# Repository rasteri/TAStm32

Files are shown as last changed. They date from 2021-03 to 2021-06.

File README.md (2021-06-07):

# TAStm32
Please see the "Projects" section for an overview of the current status of this project!

Please see the "Wiki" section for the technical details of the serial communication protocol!

### Overview

This project aims to create an easy-to-use, multi-system TAS replay device to be used on actual consoles. The name of this project comes from the fact that it is powered by a STM32F4 microcontroller.

### Prerequisites

First clone or download this repository

#### Get Python3!
Install the [latest Python 3 release](https://www.python.org/downloads/)

(You may need to log out/log in to refresh the PATH variable)

Then install the required python modules with the following command:

    python3 -m pip install -r python/requirements.txt
    
#### Linux users -- make sure you are in the dialout and plugdev groups!
    
### Compilation

#### Linux
    apt install gcc-arm-none-eabi binutils-arm-none-eabi libnewlib-arm-none-eabi
OR the equivalent in your distribution.

Then : 

    make v3
    
Or : 

    make v4
    
Depending on if you have a v3 or v4 board. (v4s came out around July 2021)

#### Windows

1. Right-click on the project > Build Configurations > Set Active, then click "Release v3" or "Release v4" depending on your board version. (v4s came out around July 2021)
1. Project > Build Project and check that the console shows no errors. The last line before "build finished" should be "arm-atollic-eabi-objcopy -O ihex TAStm32.elf TAStm32.hex".

### Flashing the firmware

#### Linux
    apt install dfu-util
OR the equivalent in your distribution

    make flash

#### Windows
1. Install Atollic TrueStudio
1. Install STM32CubeProgrammer
1. Open up the command prompt
1. Run setenv.bat included in the root directory
1. Run update.bat included in the root directory

### Usage

Dumped TAS movies are available in the [TASBot projects repo](https://github.com/dwangoac/TASBot-Projects/tree/master/replayfiles)

[Scripts to dump your own TASes](https://github.com/dwangoac/TASBot-Projects/blob/master/Dump_Scripts/)

Once you've prepared a movie dump, use it with the TAStm32. Here is one example example is here:

    python3 tastm32.py --console snes --players 1,5 --dpcm --clock 14 --transition 2123 A --blank 1 smb3_agdq.r16m

### Special Thanks
#### TheMas3212 - Aided with all things python, designing the serial communication protocol, helping with PCB design, and debugging throughout the whole process.
#### CraftedCart - Designed the awesome-looking 3D case
#### total (@tewtal) - Helped with NES/SNES protocol and debugging. Provided his code as a reference
#### booto (@booto) - Helped fix N64/GC protocols, serial-over-USB, and debugging
#### rasteri (@rasteri) - Standalone USB playback, v4 board, and more!
#### Skippy - Pretty much helped a little bit with everything: including software, hardware, advice on proper tools, and more!

dwangoAC (@dwangoac) - warmly accepting me into the TASBot community

micro500 (@micro500) - spent a lot of time teaching me how console replay devices work at a low level

true - for teaching me hardware concepts, helping me choose the perfect MCU for the job, and explaining a lot of low-level things to me

Tien Majerle (@MaJerle) - the owner of https://stm32f4-discovery.net/ helped me with the function which jumps to the DFU bootloader code

Ilari - for being an extraordinary wealth of knowledge on most topics

Serisium (@serisium) - helped with debugging and PCB design

rcombs (@rcombs) - helped with optimizing the N64 protocol

Sauraen (@sauraen) - Linux setup and installation notes, multiplayer GC/N64 support, misc. GC/N64 improvements

Derf - worked on debugging the genesis protocol together

sspx (@SuperSpyTX) - For help with finding a bug in the N64 controller identity code.

#### If I accidentally forgot to credit you, please let me know so I can fix it!

 - Ownasaurus

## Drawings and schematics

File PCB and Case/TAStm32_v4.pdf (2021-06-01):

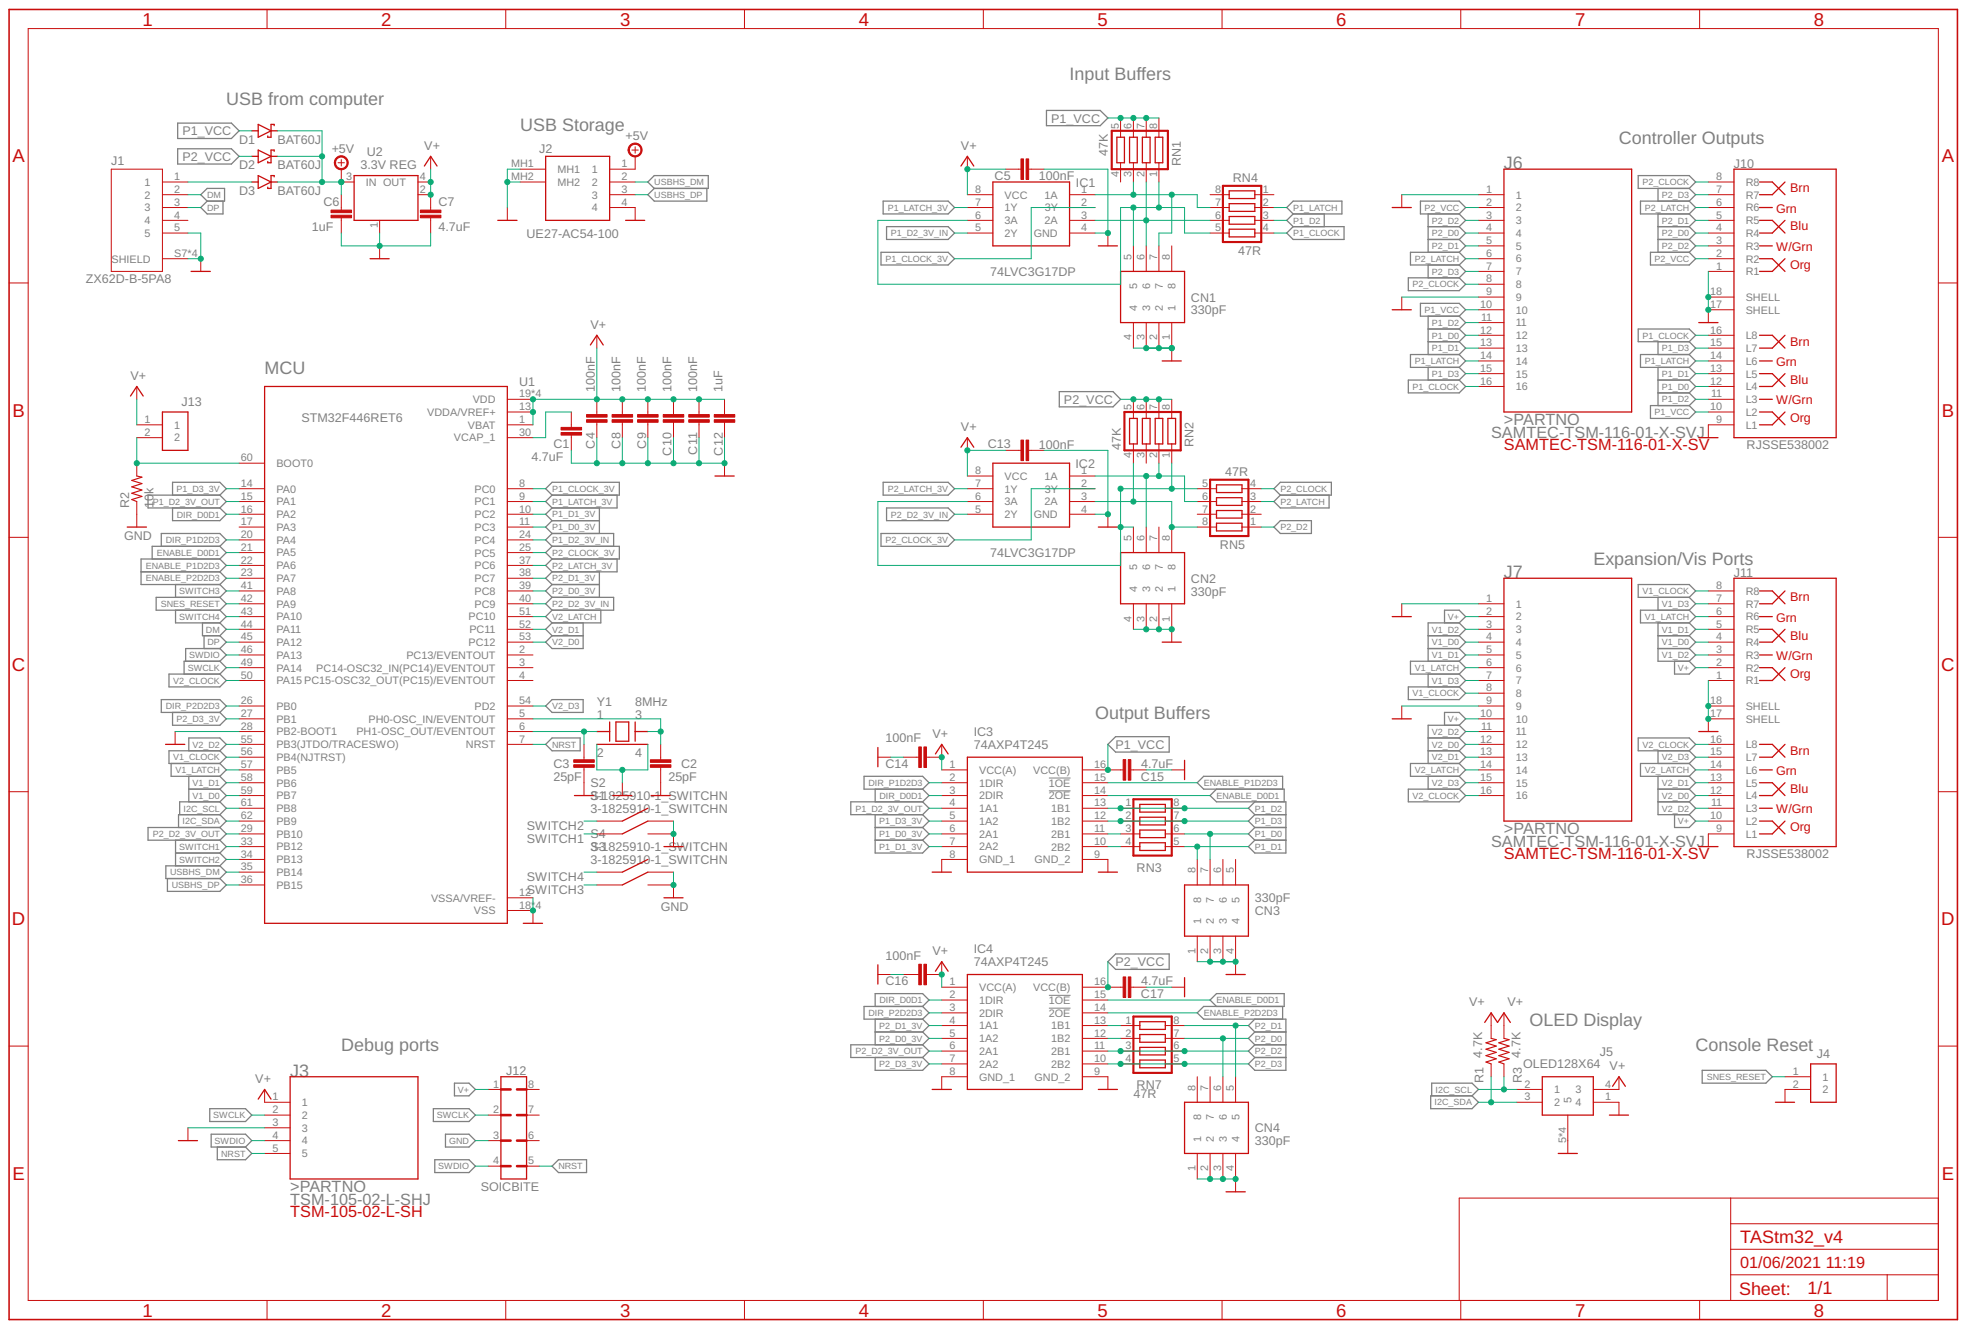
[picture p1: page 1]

Org Blu Brn W/Grn Grn

ENABLE_D0D1 | 25 PC6 P2_CLOCK_3V 37 PC7

ENABLE_P1D2D3 | P2_LATCH_3V

DIR_D0D1 3 | 1OE | ENABLE_D0D1
DIR_P2D2D3 4 | 2OE 1B1 1B2 2B1 2B2 | 13 | ENABLE_P2D2D3
P2_D1_3V 5 | | 12 2 | 7 | P2_D1
P2_D0_3V | | | | P2_D0
6 P2_D2_3V_OUT | | 11 3 | 6 | | P2_D2

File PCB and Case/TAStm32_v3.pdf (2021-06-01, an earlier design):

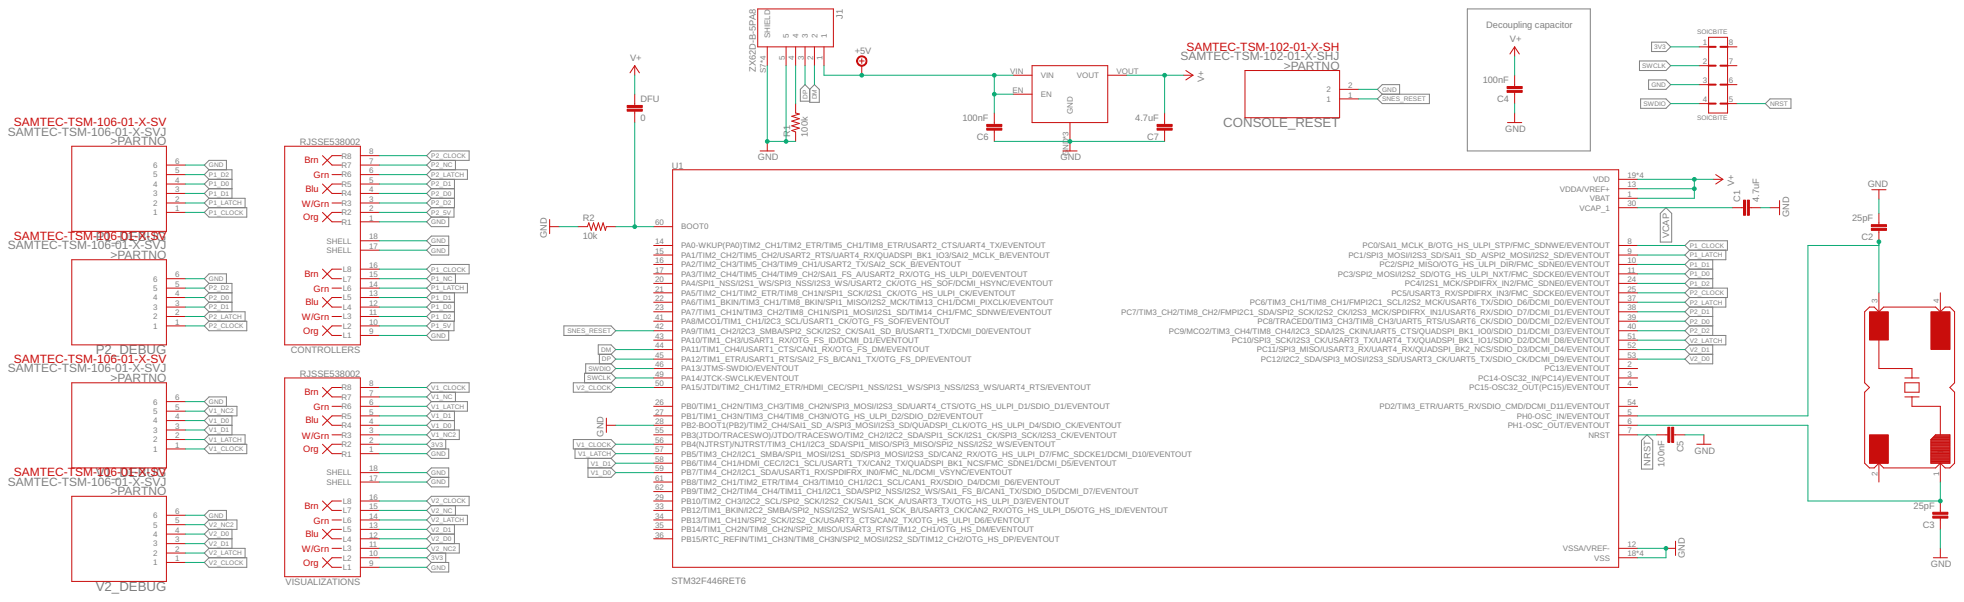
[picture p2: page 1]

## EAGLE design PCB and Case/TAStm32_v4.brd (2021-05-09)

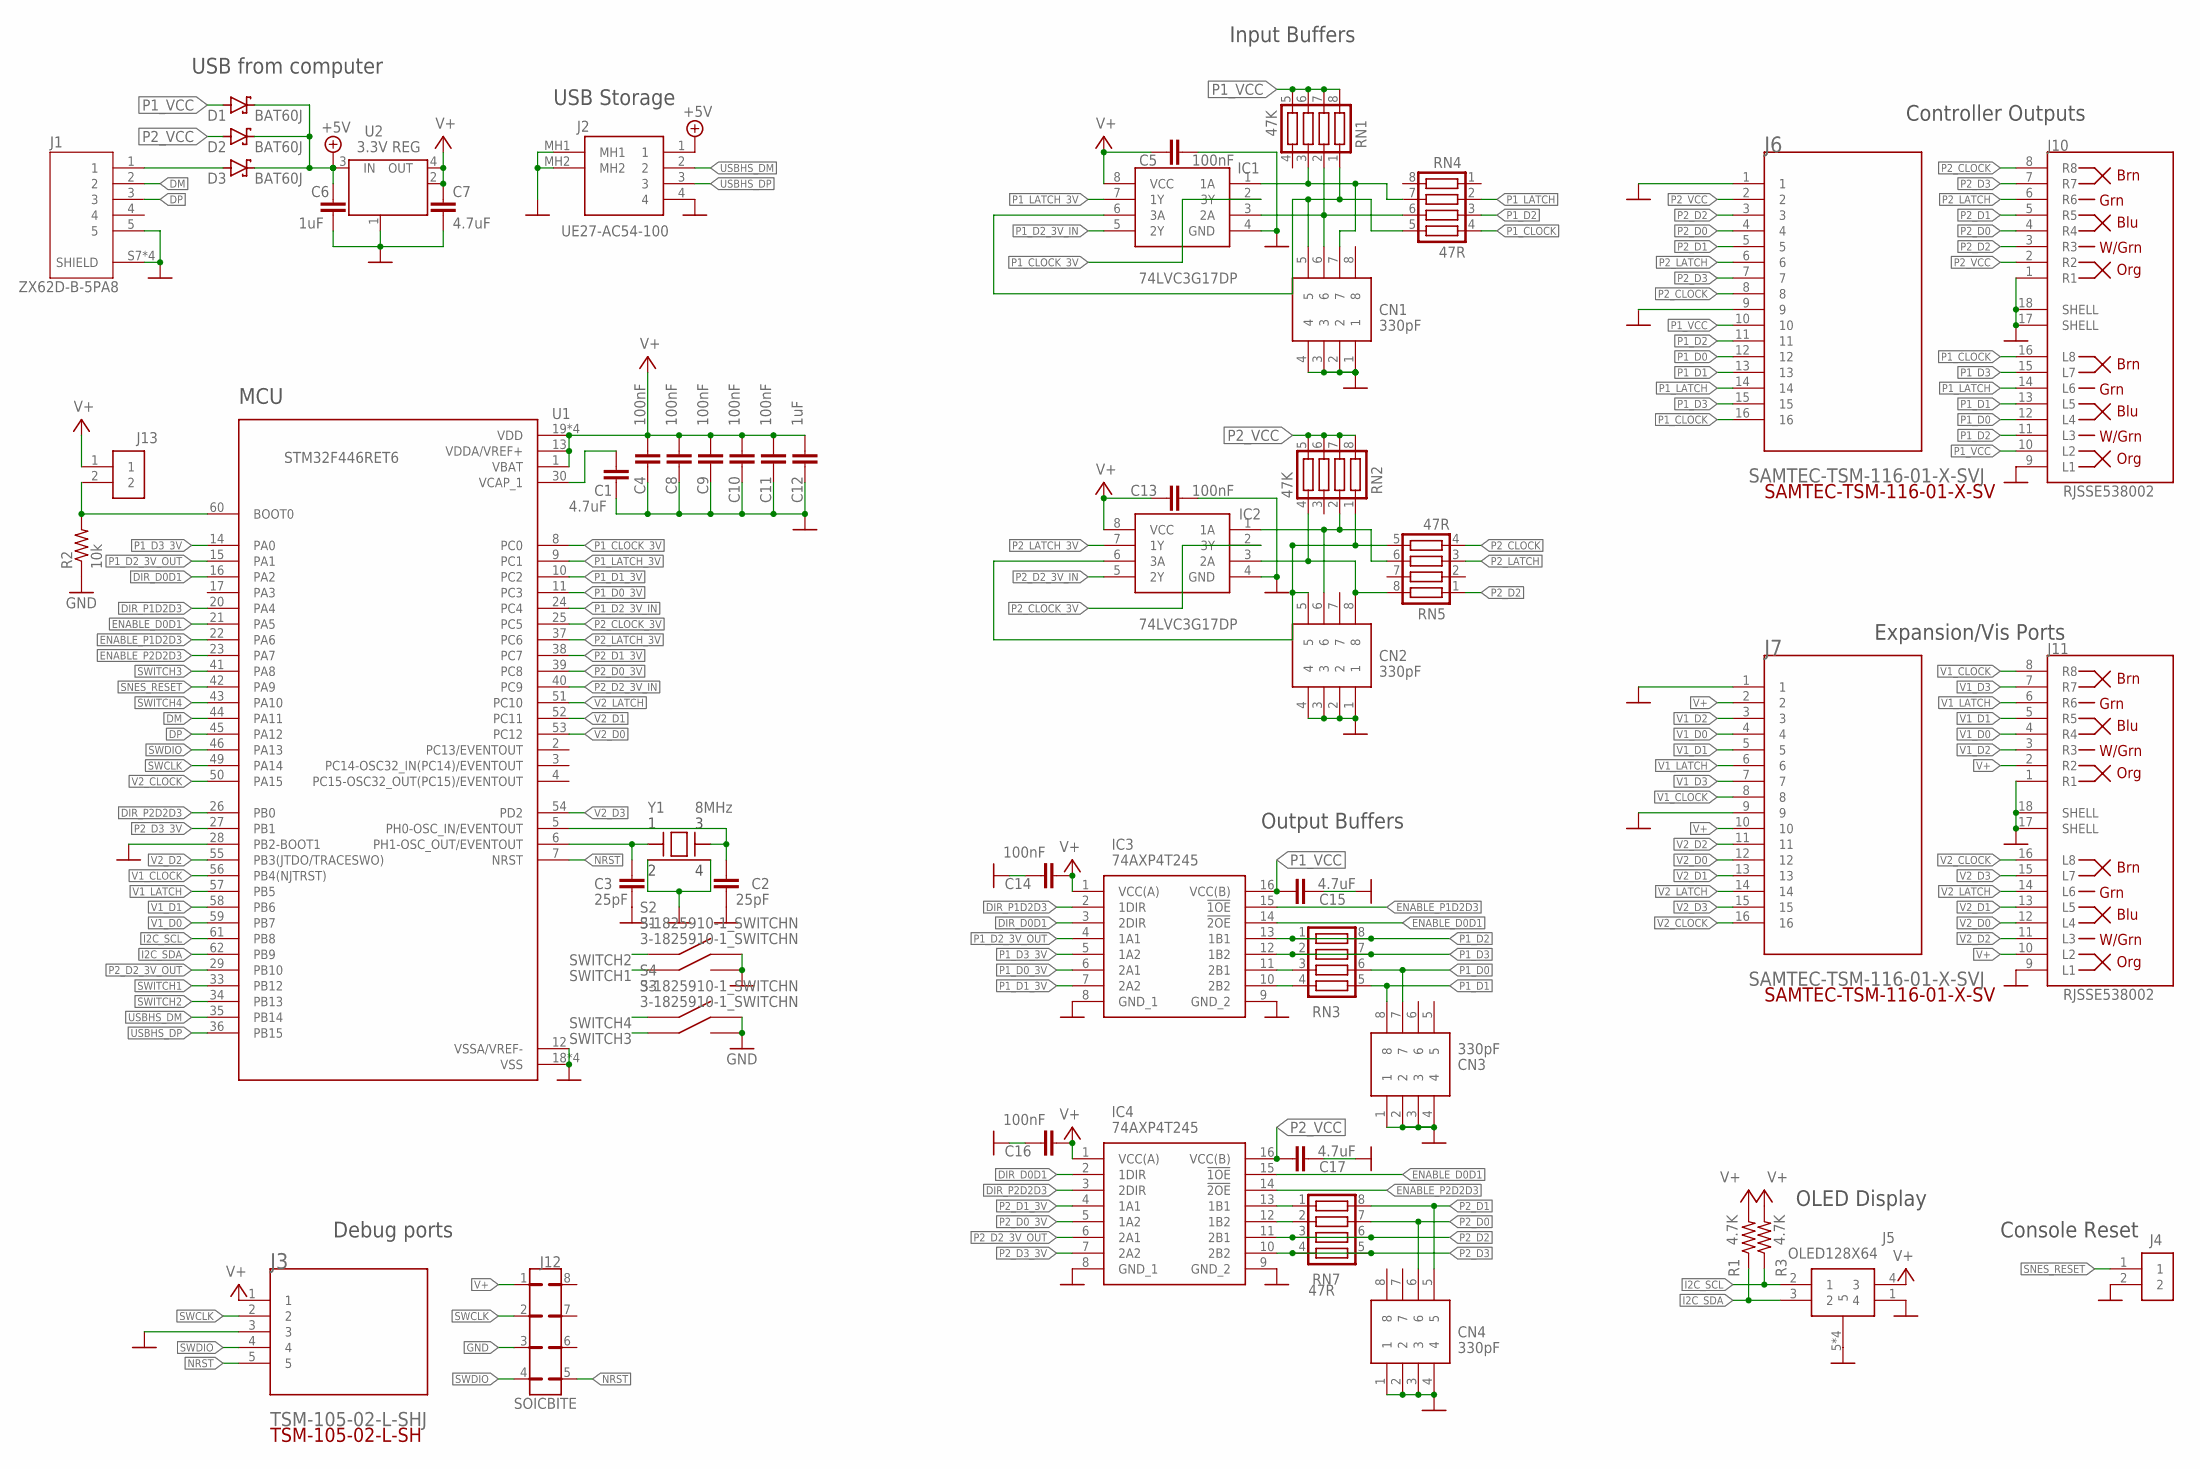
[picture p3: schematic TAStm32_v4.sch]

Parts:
C1, C7, C15, C17: 4.7uF; C0603K
C2, C3: 25pF; C0603K
C4, C5, C8, C9, C10, C11, C13, C14, C16: 100nF; C0603K
C6, C12: 1uF; C0603K
CN1, CN2, CN3, CN4: 330pF; CA0612KRX7R7BB104
D1, D2, D3: BAT60J; DIODE_SOD323_ST
IC1, IC2: 74LVC3G17DP; SOP65P400X110-8N
IC3, IC4: 74AXP4T245; SOP65P640X110-16N
J1: ZX62D-B-5PA8; HIROSE_ZX62D-B-5PA8
J2: UE27-AC54-100; UE27AC54100
J3: TSM-105-02-L-SHJ; TSM-105-02-L-SH
J4, J13: CONSOLE_RESET; SAMTEC-TSM-102-01-X-SH
J5: OLED128X64; OLED
J6, J7: SAMTEC-TSM-116-01-X-SVJ; SAMTEC-TSM-116-01-X-SV
J10, J11: RJSSE538002; AMPHENOL_RJSSE538002
J12: SOICBITE
R1, R3: 4.7K; R0805
R2: 10k; R0805
RN1, RN2: 47K; CTS742C083
RN3: CTS742C083
RN4, RN5, RN7: 47R; CTS742C083
S1, S2, S3, S4: 3-1825910-1_SWITCHN; 3-1825910-1_318259101
U1: STM32F446RET6; QFP50P1200X1200X160-64N
U2: 3.3V REG; SOT223
Y1: 8MHz; DFN-4

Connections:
+5V: C6.2, D1.C, D2.C, D3.C, J2.1, U2.3 (IN)
BOOT0: J13.2, R2.2, U1.60 (BOOT0)
DIR_D0D1: IC3.3 (2DIR), IC4.2 (1DIR), U1.16 (PA2)
DIR_P1D2D3: IC3.2 (1DIR), U1.20 (PA4)
DIR_P2D2D3: IC4.3 (2DIR), U1.26 (PB0)
DM: J1.2, U1.44 (PA11)
DP: J1.3, U1.45 (PA12)
ENABLE_D0D1: IC3.14 (!2OE), IC4.15 (!1OE), U1.21 (PA5)
ENABLE_P1D2D3: IC3.15 (!1OE), U1.22 (PA6)
ENABLE_P2D2D3: IC4.14 (!2OE), U1.23 (PA7)
GND: C1.2, C2.1, C3.1, C4.1, C5.2, C6.1, C7.1, C8.1, C9.1, C10.1, C11.1, C12.1, C13.2, C14.1, C15.2, C16.1, C17.2, CN1.1, CN1.2, CN1.3, CN1.4, CN2.1, CN2.2, CN2.3, CN2.4, CN3.1, CN3.2, CN3.3, CN3.4, CN4.1, CN4.2, CN4.3, CN4.4, IC1.4 (GND), IC2.4 (GND), IC3.8 (GND_1), IC3.9 (GND_2), IC4.8 (GND_1), IC4.9 (GND_2), J1.5, J1.S7 (SHIELD), J1.S8 (SHIELD), J1.S9 (SHIELD), J1.S10 (SHIELD), J2.4, J2.MH1, J2.MH2, J3.3, J4.2, J5.1 (4), J5.5, J5.6 (5), J5.7 (5), J5.8 (5), J6.1, J6.9, J7.1, J7.9, J10.1 (R1), J10.9 (L1), J10.17 (SHELL), J10.18 (SHELL), J11.1 (R1), J11.9 (L1), J11.17 (SHELL), J11.18 (SHELL), J12.3, R2.1, S1.3, S1.4, S2.3, S2.4, S3.3, S3.4, S4.3, S4.4, U1.12 (VSSA/VREF-), U1.18 (VSS), U1.28 (PB2-BOOT1), U1.31 (VSS), U1.47 (VSS), U1.63 (VSS), U2.1 (GND/ADJ), Y1.2, Y1.4
I2C_SCL: J5.2 (1), R3.1, U1.61 (PB8)
I2C_SDA: J5.3 (2), R1.1, U1.62 (PB9)
unnamed: D3.A, J1.1
unnamed: CN2.6, IC2.1 (1A), RN2.2, RN5.6
unnamed: C3.2, U1.6 (PH1-OSC_OUT/EVENTOUT), Y1.1
unnamed: CN2.5, IC2.6 (3A), RN2.1, RN5.5
unnamed: CN2.8, IC2.3 (2A), RN2.4, RN5.8
unnamed: IC3.11 (2B1), RN3.3
unnamed: IC3.10 (2B2), RN3.4
unnamed: IC4.12 (1B2), RN7.2
unnamed: IC4.13 (1B1), RN7.1
unnamed: CN1.7, IC1.1 (1A), RN1.3, RN4.7
unnamed: CN1.5, IC1.6 (3A), RN1.1, RN4.5
unnamed: CN1.6, IC1.3 (2A), RN1.2, RN4.6
NRST: J3.5, J12.5, U1.7 (NRST)
P1_CLOCK: J6.16, J10.16 (L8), RN4.4
P1_CLOCK_3V: IC1.2 (3Y), U1.8 (PC0)
P1_D0: CN3.7, J6.12, J10.12 (L4), RN3.6
P1_D0_3V: IC3.6 (2A1), U1.11 (PC3)
P1_D1: CN3.8, J6.13, J10.13 (L5), RN3.5
P1_D1_3V: IC3.7 (2A2), U1.10 (PC2)
P1_D2: IC3.13 (1B1), J6.11, J10.11 (L3), RN3.1, RN3.8, RN4.3
P1_D2_3V_IN: IC1.5 (2Y), U1.24 (PC4)
P1_D2_3V_OUT: IC3.4 (1A1), U1.15 (PA1)
P1_D3: IC3.12 (1B2), J6.15, J10.15 (L7), RN3.2, RN3.7
P1_D3_3V: IC3.5 (1A2), U1.14 (PA0)
P1_LATCH: J6.14, J10.14 (L6), RN4.2
P1_LATCH_3V: IC1.7 (1Y), U1.9 (PC1)
P1_VCC: C15.1, D1.A, IC3.16 (VCC(B)), J6.10, J10.10 (L2), RN1.5, RN1.6, RN1.7, RN1.8
P2_CLOCK: J6.8, J10.8 (R8), RN5.4
P2_CLOCK_3V: IC2.2 (3Y), U1.25 (PC5)
P2_D0: CN4.6, J6.4, J10.4 (R4), RN7.7
P2_D0_3V: IC4.5 (1A2), U1.39 (PC8)
P2_D1: CN4.5, J6.5, J10.5 (R5), RN7.8
P2_D1_3V: IC4.4 (1A1), U1.38 (PC7)
P2_D2: IC4.11 (2B1), J6.3, J10.3 (R3), RN5.1, RN7.3, RN7.6
P2_D2_3V_IN: IC2.5 (2Y), U1.40 (PC9)
P2_D2_3V_OUT: IC4.6 (2A1), U1.29 (PB10)
P2_D3: IC4.10 (2B2), J6.7, J10.7 (R7), RN7.4, RN7.5
P2_D3_3V: IC4.7 (2A2), U1.27 (PB1)
P2_LATCH: J6.6, J10.6 (R6), RN5.3
P2_LATCH_3V: IC2.7 (1Y), U1.37 (PC6)
P2_VCC: C17.1, D2.A, IC4.16 (VCC(B)), J6.2, J10.2 (R2), RN2.5, RN2.6, RN2.7, RN2.8
SNES_RESET: J4.1, U1.42 (PA9)
SWCLK: J3.2, J12.2, U1.49 (PA14)
SWDIO: J3.4, J12.4, U1.46 (PA13)
SWITCH1: S1.1, S1.2, U1.33 (PB12)
SWITCH2: S2.1, S2.2, U1.34 (PB13)
SWITCH3: S3.1, S3.2, U1.41 (PA8)
SWITCH4: S4.1, S4.2, U1.43 (PA10)
USBHS_DM: J2.2, U1.35 (PB14)
USBHS_DP: J2.3, U1.36 (PB15)
V1_CLOCK: J7.8, J11.8 (R8), U1.56 (PB4(NJTRST))
V1_D0: J7.4, J11.4 (R4), U1.59 (PB7)
V1_D1: J7.5, J11.5 (R5), U1.58 (PB6)
V1_D2: J7.3, J11.3 (R3)
V1_D3: J7.7, J11.7 (R7)
V1_LATCH: J7.6, J11.6 (R6), U1.57 (PB5)
V2_CLOCK: J7.16, J11.16 (L8), U1.50 (PA15)
V2_D0: J7.12, J11.12 (L4), U1.53 (PC12)
V2_D1: J7.13, J11.13 (L5), U1.52 (PC11)
V2_D2: J7.11, J11.11 (L3), U1.55 (PB3(JTDO/TRACESWO))
V2_D3: J7.15, J11.15 (L7), U1.54 (PD2)
V2_LATCH: J7.14, J11.14 (L6), U1.51 (PC10)
V+: C4.2, C5.1, C7.2, C8.2, C9.2, C10.2, C11.2, C12.2, C13.1, C14.2, C16.2, IC1.8 (VCC), IC2.8 (VCC), IC3.1 (VCC(A)), IC4.1 (VCC(A)), J3.1, J5.4 (3), J7.2, J7.10, J11.2 (R2), J11.10 (L2), J12.1, J13.1, R1.2, R3.2, U1.1 (VBAT), U1.13 (VDDA/VREF+), U1.19 (VDD), U1.32 (VDD), U1.48 (VDD), U1.64 (VDD), U2.2 (OUT), U2.4 (OUT)
VCAP: C1.1, U1.30 (VCAP_1)
XTAL1: C2.2, U1.5 (PH0-OSC_IN/EVENTOUT), Y1.3

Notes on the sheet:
USB from computer
USB Storage
MCU
Debug ports
OLED Display
Console Reset
Controller Outputs
Expansion/Vis Ports
Input Buffers
Output Buffers

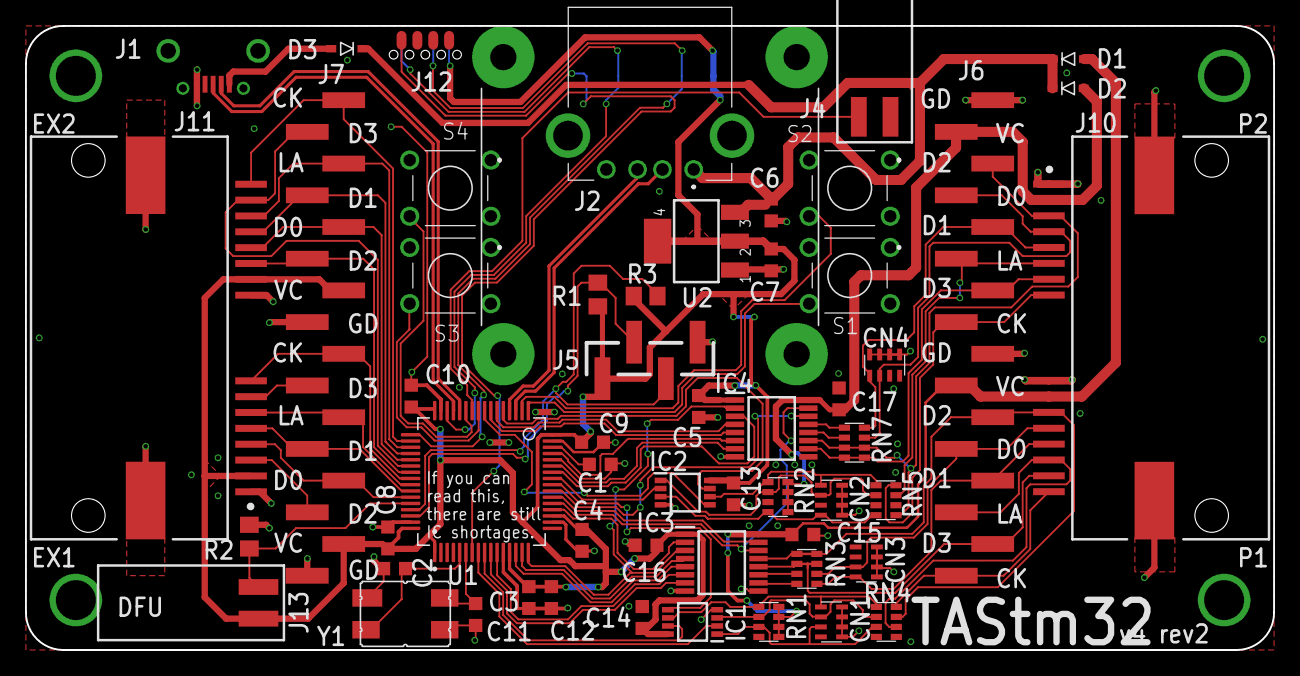
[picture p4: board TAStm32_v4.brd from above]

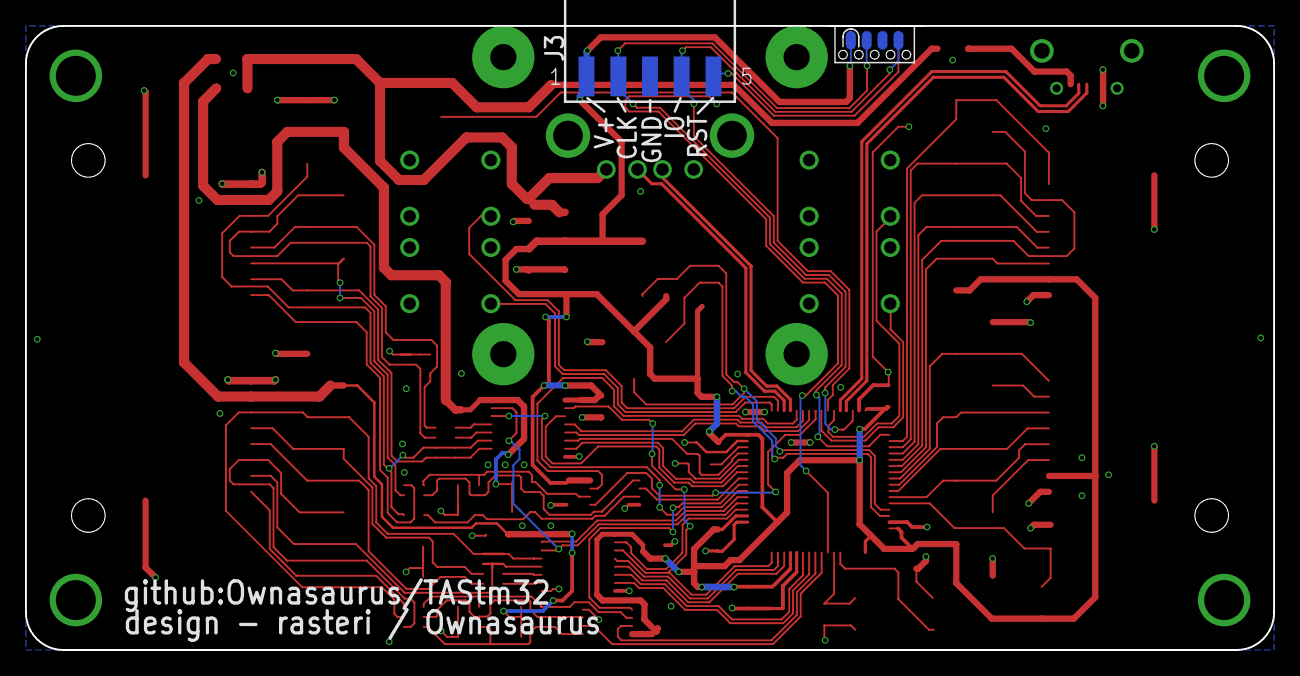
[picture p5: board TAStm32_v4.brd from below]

Board: 2 copper layers, 100.0 x 50.0 mm, 55 parts (2 on the bottom side), 78 nets.

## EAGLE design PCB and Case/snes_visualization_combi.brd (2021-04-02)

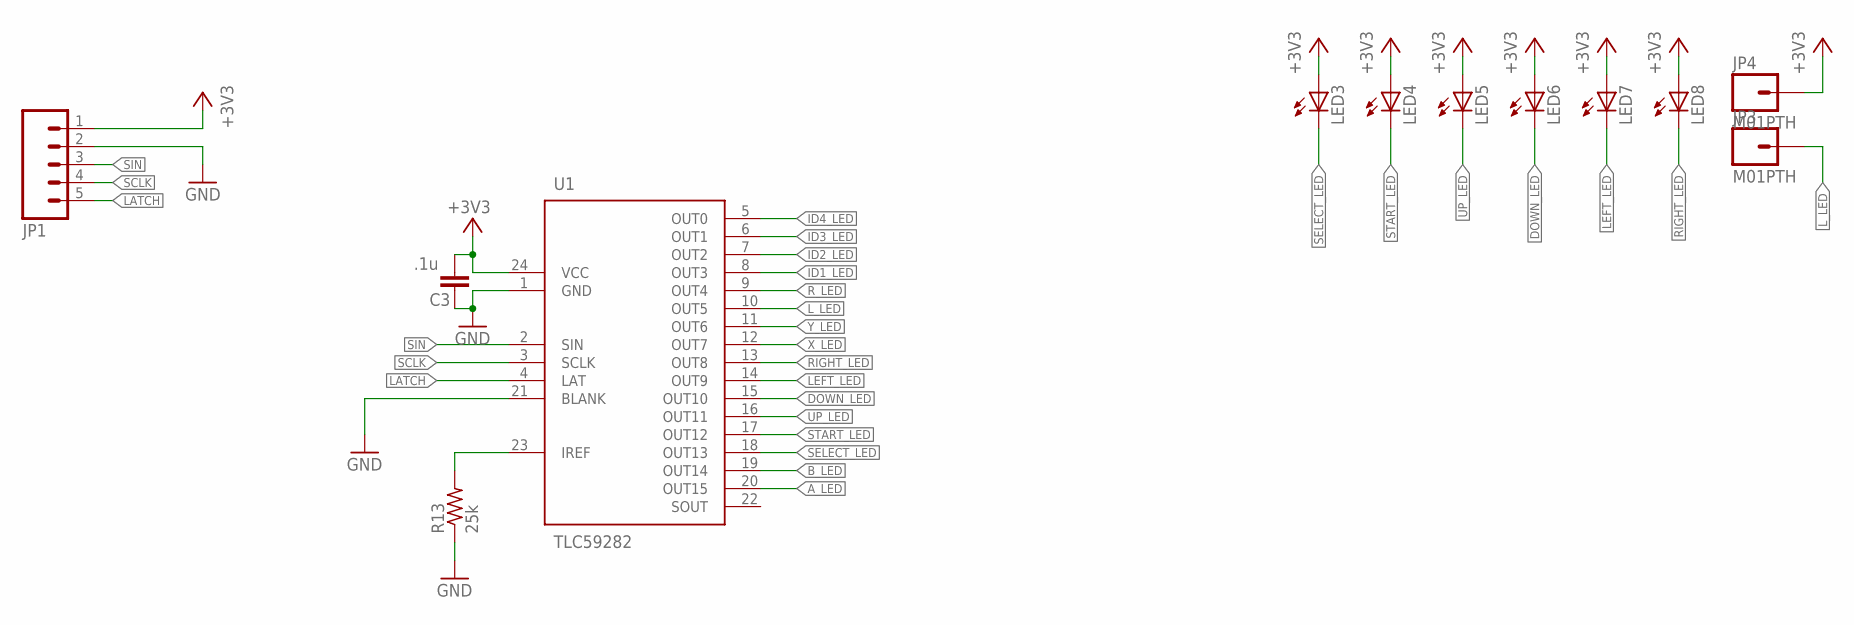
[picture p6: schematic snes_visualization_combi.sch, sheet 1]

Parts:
C3: .1u; C0603; MOUSER# 80-C0603C104K5R
JP1: M05PTH; 1X05
JP3, JP4: M01PTH; 1X01
LED3, LED4: LED3MM
LED5, LED6, LED7, LED8: LED5MM
R13: 25k; R0805
U1: TLC59282; R-PDSO-G24

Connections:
+3V3: C3.1, JP1.1, JP4.1, LED3.A, LED4.A, LED5.A, LED6.A, LED7.A, LED8.A, U1.24 (VCC); also elsewhere on the board
A_LED: U1.20 (OUT15); also elsewhere on the board
B_LED: U1.19 (OUT14); also elsewhere on the board
DOWN_LED: LED6.K (C), U1.15 (OUT10)
GND: C3.2, JP1.2, R13.1, U1.1 (GND), U1.21 (BLANK)
ID1_LED: U1.8 (OUT3); also elsewhere on the board
ID2_LED: U1.7 (OUT2); also elsewhere on the board
ID3_LED: U1.6 (OUT1); also elsewhere on the board
ID4_LED: U1.5 (OUT0); also elsewhere on the board
LATCH: JP1.5, U1.4 (LAT)
LEFT_LED: LED7.K (C), U1.14 (OUT9)
L_LED: JP3.1, U1.10 (OUT5)
unnamed: R13.2, U1.23 (IREF)
RIGHT_LED: LED8.K (C), U1.13 (OUT8)
R_LED: U1.9 (OUT4); also elsewhere on the board
SCLK: JP1.4, U1.3 (SCLK)
SELECT_LED: LED3.K (C), U1.18 (OUT13)
SIN: JP1.3, U1.2 (SIN)
START_LED: LED4.K (C), U1.17 (OUT12)
UP_LED: LED5.K (C), U1.16 (OUT11)
X_LED: U1.12 (OUT7); also elsewhere on the board
Y_LED: U1.11 (OUT6); also elsewhere on the board

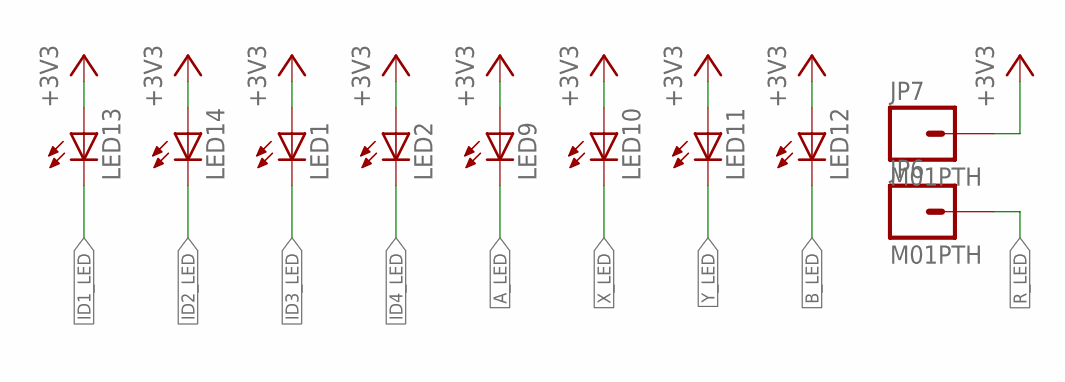
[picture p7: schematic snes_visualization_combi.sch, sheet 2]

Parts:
JP6, JP7: M01PTH; 1X01
LED1, LED2, LED9, LED10, LED11, LED12, LED13, LED14: LED5MM

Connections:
+3V3: JP7.1, LED1.A, LED2.A, LED9.A, LED10.A, LED11.A, LED12.A, LED13.A, LED14.A; also elsewhere on the board
A_LED: LED9.K (C); also elsewhere on the board
B_LED: LED12.K (C); also elsewhere on the board
ID1_LED: LED13.K (C); also elsewhere on the board
ID2_LED: LED14.K (C); also elsewhere on the board
ID3_LED: LED1.K (C); also elsewhere on the board
ID4_LED: LED2.K (C); also elsewhere on the board
R_LED: JP6.1; also elsewhere on the board
X_LED: LED10.K (C); also elsewhere on the board
Y_LED: LED11.K (C); also elsewhere on the board

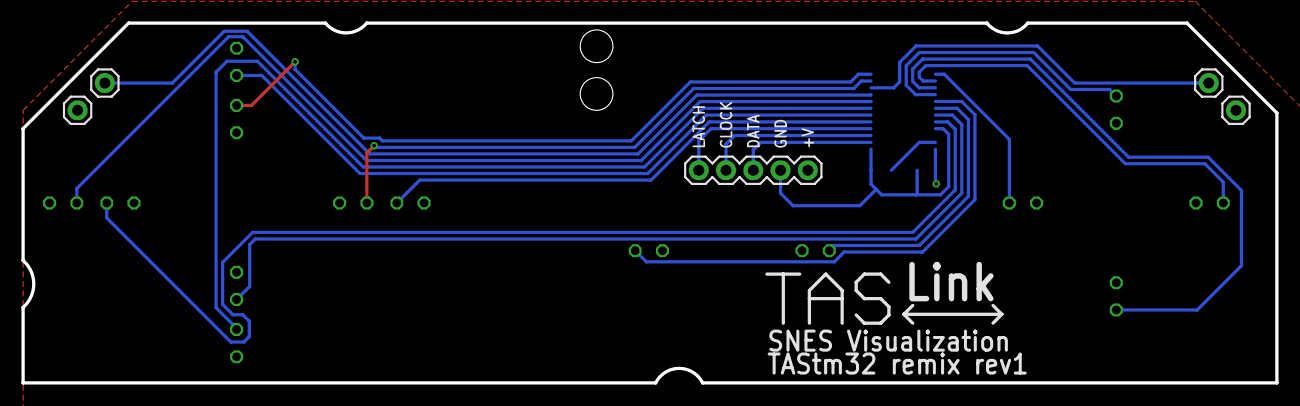
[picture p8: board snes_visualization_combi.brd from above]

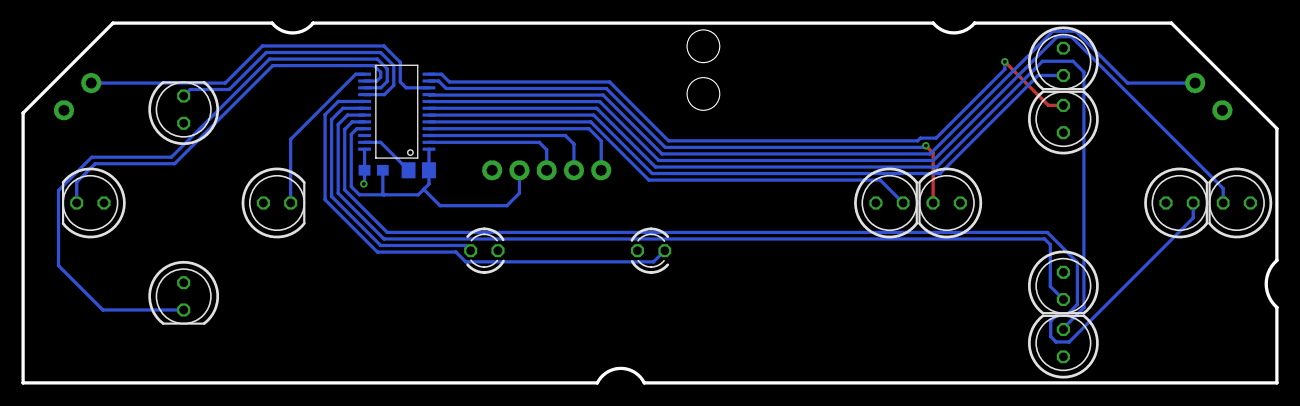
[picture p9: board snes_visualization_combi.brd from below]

Board: 2 copper layers, 116.8 x 33.5 mm, 22 parts (17 on the bottom side), 22 nets.

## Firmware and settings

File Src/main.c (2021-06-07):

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

/* Includes ------------------------------------------------------------------*/
#include "main.h"
#include "fatfs.h"
#include "usb_device.h"
#include "usb_host.h"

/* USER CODE BEGIN Includes */
#include <string.h>
#include "usbd_cdc_if.h"
#include "n64.h"
#include "TASRun.h"
#include "stm32f4xx_it.h"
#include "serial_interface.h"
#include "usbplayback/usbplayback.h"
/* USER CODE END Includes */

I2C_HandleTypeDef hi2c1;

TIM_HandleTypeDef htim2;
TIM_HandleTypeDef htim3;
TIM_HandleTypeDef htim6;
TIM_HandleTypeDef htim7;
TIM_HandleTypeDef htim10;

/* USER CODE BEGIN PV */
volatile uint8_t jumpToDFU;
/* USER CODE END PV */

void SystemClock_Config(void);
static void MX_TIM3_Init(void);
static void MX_TIM6_Init(void);
static void MX_TIM7_Init(void);
static void MX_TIM10_Init(void);
static void MX_I2C1_Init(void);
static void MX_TIM2_Init(void);
void MX_USB_HOST_Process(void);

/* USER CODE BEGIN PFP */

// Reset GPIO back to poweron state

/* USER CODE END PFP */

/**
  * @brief  The application entry point.
  * @retval int
  */
int main(void)
{
  /* USER CODE BEGIN 1 */
	// Specifies whether the OLED screen has been detected and therefore whether or not to send data to it

	uint8_t screenOK = 0;
  /* USER CODE END 1 */

  /* MCU Configuration--------------------------------------------------------*/

  /* Reset of all peripherals, Initializes the Flash interface and the Systick. */
  HAL_Init();

  /* Configure the system clock */
  SystemClock_Config();

  /* USER CODE BEGIN SysInit */
  serial_interface_reset();
  ResetGPIO();
  /* USER CODE END SysInit */

  /* Initialize all configured peripherals */
  MX_USB_DEVICE_Init();
  MX_TIM3_Init();
  MX_TIM6_Init();
  MX_TIM7_Init();
  MX_TIM10_Init();
  MX_FATFS_Init();
  MX_USB_HOST_Init();
  MX_I2C1_Init();
  MX_TIM2_Init();
  /* USER CODE BEGIN 2 */

  jumpToDFU = 0;

  // Check the OLED screen is there and initialize it if so
  screenOK = USB_Playback_Init();

  // Only start the input process timer if the screen has been detected
  if (screenOK) HAL_TIM_Base_Start_IT(&htim2);

  /* USER CODE END 2 */

  /* Infinite loop */
  /* USER CODE BEGIN WHILE */
  while (1)
  {
    /* USER CODE END WHILE */
    MX_USB_HOST_Process();

    /* USER CODE BEGIN 3 */
	  if(jumpToDFU == 1)
	  {
		  JumpToBootLoader();
	  }

	  // Only run USB playback task if screen has been detected
	  if (screenOK)
		  USB_Playback_Task();

  }
  /* USER CODE END 3 */
}

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
/* USER CODE BEGIN 4 */
void ReInitClockTimers(void)
{

	TIM_MasterConfigTypeDef sMasterConfig = {0};
	sMasterConfig.MasterOutputTrigger = TIM_TRGO_RESET;
	sMasterConfig.MasterSlaveMode = TIM_MASTERSLAVEMODE_DISABLE;

	// re-init tim6
	if (HAL_TIM_Base_Init(&htim6) != HAL_OK)
	{
		Error_Handler();
	}
	if (HAL_TIMEx_MasterConfigSynchronization(&htim6, &sMasterConfig) != HAL_OK)
	{
		Error_Handler();
	}

	// re-init tim7
	if (HAL_TIM_Base_Init(&htim7) != HAL_OK)
	{
		Error_Handler();
	}
	if (HAL_TIMEx_MasterConfigSynchronization(&htim7, &sMasterConfig) != HAL_OK)
	{
		Error_Handler();
	}

}

// Many thanks to Tien Majerle, owner of https://stm32f4-discovery.net/, for help with this function
void JumpToBootLoader(void) {
	void (*SysMemBootJump)(void);

	// De-init USB
	MX_USB_DEVICE_DeInit();
	MX_USB_HOST_DeInit();

	// Disable all of our interrupts (except systick which will be handled later)
	HAL_NVIC_DisableIRQ(EXTI0_IRQn);
	HAL_NVIC_DisableIRQ(EXTI1_IRQn);
	HAL_NVIC_DisableIRQ(EXTI4_IRQn);
	HAL_NVIC_DisableIRQ(EXTI9_5_IRQn);
	HAL_NVIC_DisableIRQ(OTG_FS_IRQn);
	HAL_NVIC_DisableIRQ(TIM3_IRQn);
	HAL_NVIC_DisableIRQ(TIM6_DAC_IRQn);
	HAL_NVIC_DisableIRQ(TIM7_IRQn);
	HAL_NVIC_DisableIRQ(TIM1_UP_TIM10_IRQn);
	HAL_NVIC_DisableIRQ(SysTick_IRQn);

	// De-init timers
	HAL_TIM_Base_DeInit(&htim3);
	HAL_TIM_Base_DeInit(&htim6);
	HAL_TIM_Base_DeInit(&htim7);
	HAL_TIM_Base_DeInit(&htim10);

	// clear all interrupts
	while (HAL_NVIC_GetPendingIRQ(EXTI0_IRQn))
	{
		__HAL_GPIO_EXTI_CLEAR_IT(P1_CLOCK_Pin);
		HAL_NVIC_ClearPendingIRQ(EXTI0_IRQn);
	}
	while (HAL_NVIC_GetPendingIRQ(EXTI1_IRQn))
	{
		__HAL_GPIO_EXTI_CLEAR_IT(P1_LATCH_Pin);
		HAL_NVIC_ClearPendingIRQ(EXTI1_IRQn);
	}
	while (HAL_NVIC_GetPendingIRQ(EXTI4_IRQn))
	{
		__HAL_GPIO_EXTI_CLEAR_IT(P1_DATA_2_Pin);
		HAL_NVIC_ClearPendingIRQ(EXTI4_IRQn);
	}
	while (HAL_NVIC_GetPendingIRQ(EXTI9_5_IRQn))
	{
		__HAL_GPIO_EXTI_CLEAR_IT(P2_CLOCK_Pin);
		__HAL_GPIO_EXTI_CLEAR_IT(P2_DATA_2_Pin);
		HAL_NVIC_ClearPendingIRQ(EXTI9_5_IRQn);
	}
	while (HAL_NVIC_GetPendingIRQ(TIM3_IRQn))
	{
		HAL_NVIC_ClearPendingIRQ(TIM3_IRQn);
	}
	while (HAL_NVIC_GetPendingIRQ(TIM6_DAC_IRQn))
	{
		HAL_NVIC_ClearPendingIRQ(TIM6_DAC_IRQn);
	}
	while (HAL_NVIC_GetPendingIRQ(TIM7_IRQn))
	{
		HAL_NVIC_ClearPendingIRQ(TIM7_IRQn);
	}
	while (HAL_NVIC_GetPendingIRQ(TIM7_IRQn))
	{
		HAL_NVIC_ClearPendingIRQ(TIM7_IRQn);
	}
	while (HAL_NVIC_GetPendingIRQ(TIM1_UP_TIM10_IRQn))
	{
		HAL_NVIC_ClearPendingIRQ(TIM1_UP_TIM10_IRQn);
	}
	while (HAL_NVIC_GetPendingIRQ(OTG_FS_IRQn))
	{
		HAL_NVIC_ClearPendingIRQ(OTG_FS_IRQn);
	}

	// Prepare to jump
	volatile uint32_t addr = 0x1FFF0000;

	// reset RCC back to default values
	HAL_RCC_DeInit();

	// clear SysTick
	SysTick->CTRL = 0;
	SysTick->LOAD = 0;
	SysTick->VAL = 0;

	// remaps the address of the system memory to 0x00000000
	// necessary for proper transition to bootloader
	SYSCFG->MEMRMP = 0x01;

	// sets destination address of the jump. note it is one word into the bootloader code which is the first instruction
	SysMemBootJump = (void (*)(void)) (*((uint32_t *)(addr + 4)));

	// sets the stack poitner to the first word of the bootloader code
	__set_MSP(*(uint32_t *)addr);

	// jump!
	SysMemBootJump();
}

/* USER CODE END 4 */
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


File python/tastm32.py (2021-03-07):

#!/usr/bin/env python3
import sys
import os
import serial
import struct
import time
import gc
import psutil

import serial_helper
import argparse_helper

import r08, r16m, m64, dtm, rgen

DEBUG = False

int_buffer = 1024 # internal buffer size on replay device

latches_per_bulk_command = 28
packets = 4

VALID_PLAYERS = {
    "n64": (1,),
    "snes": (1,2,3,4,5,6,7,8,),
    "nes": (1,5,),
    "gc": (1,),
    "genesis": (1,5,)
}

int_to_byte_struct = struct.Struct('B')
def int_to_byte(interger):
    return int_to_byte_struct.pack(interger)

class TAStm32():
    def __init__(self, ser):
        att = 0
        while att < 5:
            try:
                self.ser = serial.Serial(ser, 115200, timeout=0)
                break
            except serial.SerialException:
                att += 1
                self.ser = None
                continue
        if self.ser == None:
            print ('ERROR: the specified interface (' + ser + ') is in use')
            sys.exit(0)
        else:
            self.activeRuns = {b'A': False, b'B': False, b'C': False, b'D': False}

    def get_run_prefix(self):
        if self.activeRuns[b'A']:
            if self.activeRuns[b'B']:
                if self.activeRuns[b'C']:
                    if self.activeRuns[b'D']:
                        return None
                    else:
                        self.activeRuns[b'D'] = True
                        return b'D'
                else:
                    self.activeRuns[b'C'] = True
                    return b'C'
            else:
                self.activeRuns[b'B'] = True
                return b'B'
        else:
            self.activeRuns[b'A'] = True
            return b'A'

    def write(self, data):
        count = self.ser.write(data)
        if DEBUG and data != b'':
            print('S:', data)
        return count

    def read(self, count):
        data = self.ser.read(count)
        if DEBUG and data != b'':
            print('R:', data)
        return data

    def reset(self):
        c = self.read(1)
        if c == '':
            pass
        else:
            numBytes = self.ser.inWaiting()
            if numBytes > 0:
                c += self.read(numBytes)
        self.write(b'R')
        time.sleep(0.1)
        data = self.read(2)
        if data == b'\x01R':
            return True
        else:
            raise RuntimeError('Error during reset')

    def power_on(self):
        self.write(b'P1')

    def power_off(self):
        self.write(b'P0')

    def power_soft_reset(self):
        self.write(b'PS')

    def power_hard_reset(self):
        self.write(b'PH')

    def set_bulk_data_mode(self, prefix, mode):
        command = b''.join([b'Q', prefix, mode])
        self.write(command)

    def send_transition(self, prefix, frame, mode):
        if self.activeRuns[prefix]:
            command = ''
            if mode == b'N':
                # Set Normal Mode
                command = b''.join([b'T', prefix, mode, struct.pack('I', frame)])
            elif mode == b'A':
                # Set ACE Mode
                command = b''.join([b'T', prefix, mode, struct.pack('I', frame)])
            elif mode == b'S':
                # Set Soft Reset
                command = b''.join([b'T', prefix, mode, struct.pack('I', frame)])
            elif mode == b'H':
                # Set Hard Reset
                command = b''.join([b'T', prefix, mode, struct.pack('I', frame)])
            if command != '':
                self.write(command)

    def send_latchtrain(self, prefix, latchtrain):
        if self.activeRuns[prefix]:
            command = b''.join([b'U', prefix, struct.pack('H', len(latchtrain)), *[struct.pack('H', i) for i in latchtrain]])
            self.write(command)

    def setup_run(self, console, players=[1], dpcm=False, overread=False, clock_filter=0):
        prefix = self.get_run_prefix()
        if prefix == None:
            raise RuntimeError('No Free Run')
        vp = VALID_PLAYERS.get(console, ())
        if console == 'n64':
            cbyte = b'M'
            pbyte = 0
            for player in players:
                p = int(player)
                if p in vp:
                    pbyte = pbyte ^ 2**(8-p)
                else:
                    raise RuntimeError('Invalid player for N64')
            sbyte = 0
        elif console == 'snes':
            cbyte = b'S'
            pbyte = 0
            for player in players:
                p = int(player)
                if p in vp:
                    pbyte = pbyte ^ 2**(8-p)
                else:
                    raise RuntimeError('Invalid player for SNES')
            sbyte = 0
            if dpcm:
                sbyte = sbyte ^ 0x80
            if overread:
                sbyte = sbyte ^ 0x40
            if clock_filter:
                sbyte = sbyte + clock_filter
        elif console == 'nes':
            cbyte = b'N'
            pbyte = 0
            for player in players:
                p = int(player)
                if p in vp:
                    pbyte = pbyte ^ 2**(8-p)
                else:
                    raise RuntimeError('Invalid player for NES')
            sbyte = 0
            if dpcm:
                sbyte = sbyte ^ 0x80
            if overread:
                sbyte = sbyte ^ 0x40
            if clock_filter:
                sbyte = sbyte + clock_filter
        elif console == 'gc':
            cbyte = b'G'
            pbyte = 0
            for player in players:
                p = int(player)
                if p in vp:
                    pbyte = pbyte ^ 2**(8-p)
                else:
                    raise RuntimeError('Invalid player for GC')
            sbyte = 0
        elif console == 'genesis':
            cbyte = b'J'
            pbyte = 0
            sbyte = 0
            for player in players:
                p = int(player)
                if p in vp:
                    pbyte = pbyte ^ 2**(8-p)
                else:
                    raise RuntimeError('Invalid player for Genesis')
        command = b'S' + prefix + cbyte + int_to_byte(pbyte) + int_to_byte(sbyte)
        self.write(command)
        time.sleep(0.1)
        data = self.read(2)
        if data == b'\x01S':
            return prefix
        else:
            self.activeRuns[prefix] = False
            raise RuntimeError('Error during setup')
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

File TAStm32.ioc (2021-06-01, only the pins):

Mcu.UserName=STM32F446RETx
PA0-WKUP.GPIO_Label=P1_DATA_3
PA0-WKUP.Signal=GPIO_Output
PA1.GPIO_Label=P1_DATA_2_OUT
PA1.Signal=GPIO_Input
PA10.GPIO_Label=PA10
PA10.Signal=GPIO_Input
PA11.Signal=USB_OTG_FS_DM
PA12.Signal=USB_OTG_FS_DP
PA13.GPIO_Label=TMS
PA13.Signal=SYS_JTMS-SWDIO
PA14.GPIO_Label=TCK
PA14.Signal=SYS_JTCK-SWCLK
PA15.GPIO_Label=V2_CLOCK
PA15.Signal=GPIO_Output
PA2.GPIO_Label=DIR_D0D1
PA2.Signal=GPIO_Output
PA3.GPIO_Label=PA3
PA3.Signal=GPIO_Input
PA4.GPIO_Label=DIR_P1D2D3
PA4.Signal=GPIO_Output
PA5.GPIO_Label=ENABLE_D0D1
PA5.Signal=GPIO_Output
PA6.GPIO_Label=ENABLE_P1D2D3
PA6.Signal=GPIO_Output
PA7.GPIO_Label=ENABLE_P2D2D3
PA7.Signal=GPIO_Output
PA8.GPIO_Label=PA8
PA8.Signal=GPIO_Input
PA9.GPIO_Label=SNES_RESET
PA9.Signal=GPIO_Output
PB0.GPIO_Label=DIR_P2D2D3
PB0.Signal=GPIO_Output
PB1.GPIO_Label=P2_DATA_3
PB1.Signal=GPIO_Output
PB10.GPIO_Label=P2_DATA_2_OUT
PB10.Signal=GPIO_Output
PB12.GPIO_Label=PB12
PB12.Signal=GPIO_Input
PB13.GPIO_Label=PB13
PB13.Signal=GPIO_Input
PB14.Signal=USB_OTG_HS_DM
PB15.Signal=USB_OTG_HS_DP
PB3.GPIO_Label=V1_DATA_2
PB3.Signal=GPIO_Output
PB4.GPIO_Label=V1_CLOCK
PB4.Signal=GPIO_Output
PB5.GPIO_Label=V1_LATCH
PB5.Signal=GPIO_Output
PB6.GPIO_Label=V1_DATA_1
PB6.Signal=GPIO_Output
PB7.GPIO_Label=V1_DATA_0
PB7.Signal=GPIO_Output
PB8.Signal=I2C1_SCL
PB9.Signal=I2C1_SDA
PC0.GPIO_Label=P1_CLOCK
PC0.Signal=GPXTI0
PC1.GPIO_Label=P1_LATCH
PC1.Signal=GPXTI1
PC10.GPIO_Label=V2_LATCH
PC10.Signal=GPIO_Output
PC11.GPIO_Label=V2_DATA_1
PC11.Signal=GPIO_Output
PC12.GPIO_Label=V2_DATA_0
PC12.Signal=GPIO_Output
PC13.GPIO_Label=PC13
PC13.Signal=GPIO_Input
PC14-OSC32_IN.GPIO_Label=PC14
PC14-OSC32_IN.Signal=GPIO_Input
PC15-OSC32_OUT.GPIO_Label=PC15
PC15-OSC32_OUT.Signal=GPIO_Output
PC2.GPIO_Label=P1_DATA_1
PC2.Signal=GPIO_Input
PC3.GPIO_Label=P1_DATA_0
PC3.Signal=GPIO_Input
PC4.GPIO_Label=P1_DATA_2
PC4.Signal=GPXTI4
PC5.GPIO_Label=P2_CLOCK
PC5.Signal=GPXTI5
PC6.GPIO_Label=P2_LATCH
PC6.Signal=GPIO_Input
PC7.GPIO_Label=P2_DATA_1
PC7.Signal=GPIO_Input
PC8.GPIO_Label=P2_DATA_0
PC8.Signal=GPIO_Input
PC9.GPIO_Label=P2_DATA_2
PC9.Signal=GPIO_Input
PD2.GPIO_Label=V2_DATA_3
PD2.Signal=GPIO_Output
PH0-OSC_IN.Signal=RCC_OSC_IN
PH1-OSC_OUT.Signal=RCC_OSC_OUT

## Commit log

2020-02-17 WIP json settings file
    --save <file> to store setting to file
    --load <file> to load settings from file
    --nomovie to skip storing movie information in file
    [argparse_helper.py, save_handler.py, tastm32.py]
2020-03-28 Handle crash on runs that are smaller than buffer (line 225), fix typo on line 276, fix crash when no transitions defined (line 232)
    [tastm32.py]
2020-03-28 started basic cli framework
2020-03-30 revised code to prepare first frame
2020-04-07 - test negative blank frame count
2020-06-04 genesis framework in place except for timer. untested.
2020-06-05 added timer config for GEN. testing still needed
2020-06-06 fixed bugs in timer, communication, and python; still not yet working
    [serial_interface.c]
2020-06-06 fixed interrupt priority and gmv bit polarity
    [serial_interface.c]
2020-06-06 - Fix blankframe logic for Genesis
    [tastm32.py]
2020-06-08 - Replace gmv parser with rgen parser due to lagframes
    [rgen.py, tastm32.py]
2020-06-10 functional 3 button. fixed poweron issue
    [TASRun.c, main.c, serial_interface.c]
2020-06-23 fixing some nes/snes bugs
    [TASRun.c, serial_interface.c]
2020-06-24 dont know why runs bug sometimes
    [serial_interface.c]
2020-11-19 Added v4 PCB
    [TAStm32_v4.brd, TAStm32_v4.sch]
2020-11-19 silkscreen cleanup
    [TAStm32_v4.brd, TAStm32_v4.sch]
2020-11-19 add i2c resistors, cleanups
    [TAStm32_v4.brd, TAStm32_v4.sch]
2020-11-22 more tweaks
    [TAStm32_v4.brd, TAStm32_v4.sch]
2020-12-31 yet more cleanups
    [TAStm32_v4.brd, TAStm32_v4.sch]
2021-01-03 ye more cleanups
    [TAStm32_v4.sch]
2021-01-06 more tidyups
    [TAStm32_v4.brd]
2021-01-14 3D stuff
    [TAStm32_v4.brd, TAStm32_v4.sch]
2021-01-15 3D packages
    [TAStm32_v4.brd, TAStm32_v4.sch]
2021-01-22 Started adding level translators
    [TAStm32_v4.brd, TAStm32_v4.sch]
2021-01-22 added note
    [TAStm32_v4.sch]
2021-01-26 More notes
    [TAStm32_v4.sch]
2021-01-31 different level translators
    [TAStm32_v4.brd, TAStm32_v4.sch]
2021-02-08 another different level converter, routing
    [TAStm32_v4.brd, TAStm32_v4.sch]
2021-02-14 data line series resistors, separate enables for clk/lat, updated ioc file
    [TAStm32_v4.brd, TAStm32_v4.sch]
2021-02-16 Pin reshuffle for proto
    [TAStm32_v4.brd, TAStm32_v4.sch]
2021-02-16 more pin shuffling
2021-02-17 Buffer reset and per-console setup routines
    [TASRun.c, TASRun.h, TAStm32.ioc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]
2021-03-07 more new buffers
    [TAStm32_v4.brd, TAStm32_v4.sch]
2021-03-07 bleh updates
    [TAStm32_v4.brd, TAStm32_v4.sch]
2021-03-08 more code work
    [TAStm32_v4.brd, TAStm32_v4.sch]
2021-03-17 new new new new buffers
    [TAStm32_v4.brd, TAStm32_v4.sch]
2021-03-21 new buffer funtimes
    [TAStm32_v4.brd, TAStm32_v4.sch]
2021-03-28 no airwires!
    [TAStm32_v4.brd, TAStm32_v4.sch]
2021-03-28 v4 r2 silkscreen cleanup, combi vis board
    [TAStm32_v4.brd, snes_visualization_combi.brd, snes_visualization_combi.sch]
2021-03-29 more silkscreen cleanup
    [TAStm32_v4.brd, TAStm32_v4.sch]
2021-03-29 yet more silkscreen cleanup
    [TAStm32_v4.brd]
2021-03-29 spacing out components
    [TAStm32_v4.brd, TAStm32_v4.sch]
2021-03-31 more tidying
    [TAStm32_v4.brd]
2021-04-02 ground fill on top
    [TAStm32_v4.brd, TAStm32_v4.sch]
2021-04-02 rerouted vis board, rev2 cleanups
    [TAStm32_v4.brd, snes_visualization_combi.brd]
2021-04-05 more board tidyups
    [TAStm32_v4.brd, TAStm32_v4.sch]
2021-05-09 part number updates
    [TAStm32_v4.brd, TAStm32_v4.sch]
2021-05-14 code for v4r2 PCB
2021-06-03 v3/v4 board work

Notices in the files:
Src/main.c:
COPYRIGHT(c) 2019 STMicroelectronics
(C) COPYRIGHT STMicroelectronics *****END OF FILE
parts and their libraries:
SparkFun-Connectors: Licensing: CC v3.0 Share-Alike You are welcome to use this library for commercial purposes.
